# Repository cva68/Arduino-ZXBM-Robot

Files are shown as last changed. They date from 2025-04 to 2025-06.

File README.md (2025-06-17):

# Arduino ZXBM Robot
Chassis, PCB and Software to create an Arduino robot, including a custom motor driver shield based on the [ZXBM5210 motor driver](https://www.diodes.com/assets/Datasheets/products_inactive_data/ZXBM5210.pdf), and a chassis to hold two ["TT" geared DC motors](https://www.adafruit.com/product/3777). 

The Arduino shield design can be found in [hw](hw), and the robot chassis design can be found in [chassis](/chassis). Modules for interfacing with the shield can be found in [lib](/lib), and example control code is in [src](/src).

## Chassis
This chassis is specifically designed for the **Univeristy of Canterbury** Arduino Uno clone. The mount positions will need to be modified to be used with a standard Arduino Uno.

This is designed for 3D printing. Support will only be needed for the overhangs on the top of the chassis that are used to support the Arduino.

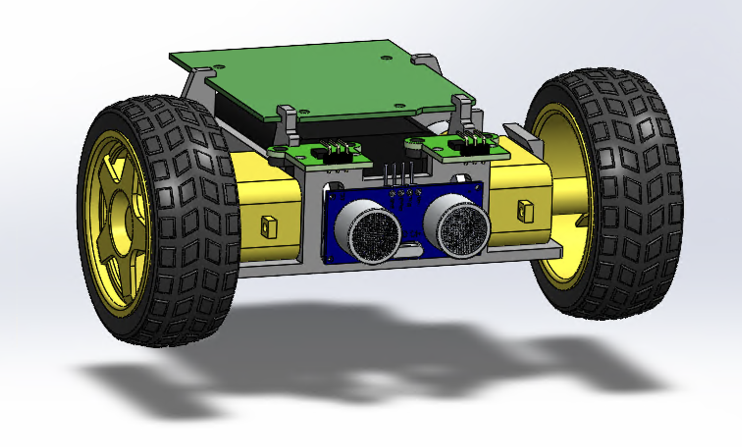
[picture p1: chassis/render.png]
Render of robot chassis


## Control Hardware

Designed in KiCad. [MotorDriverShield.kicad_pcb](hw/MotorDriverShield.kicad_pcb) and [MotorDriverShield.kicad_sch](hw/MotorDriverShield.kicad_sch) can be loaded into KiCad to modify the schematic or export Gerber files.

### Schematic
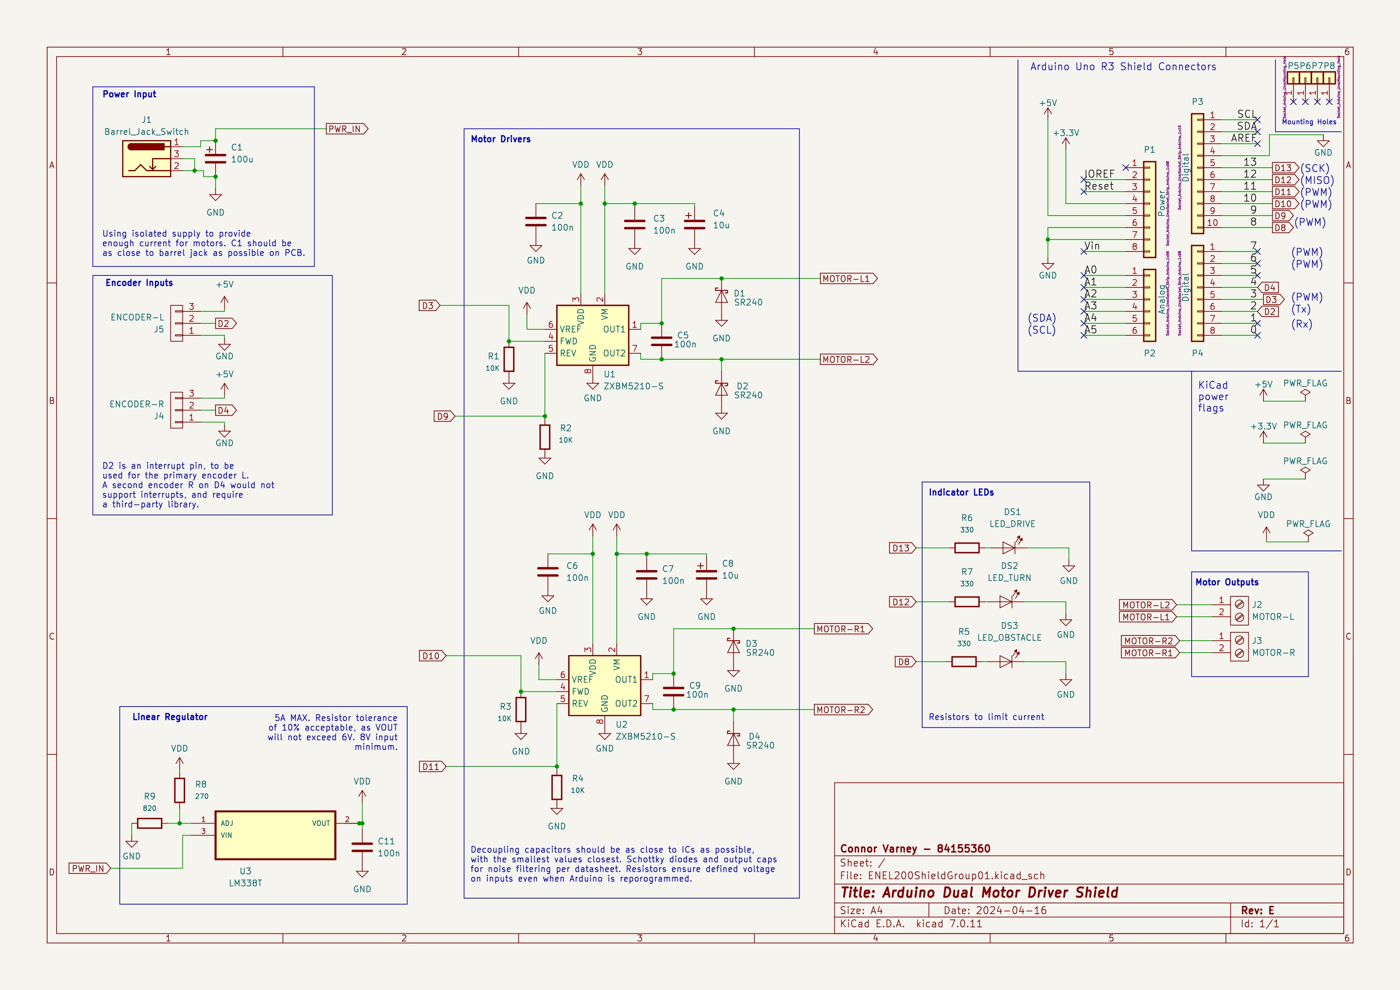
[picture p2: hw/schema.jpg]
Robot Schematic


### PCB
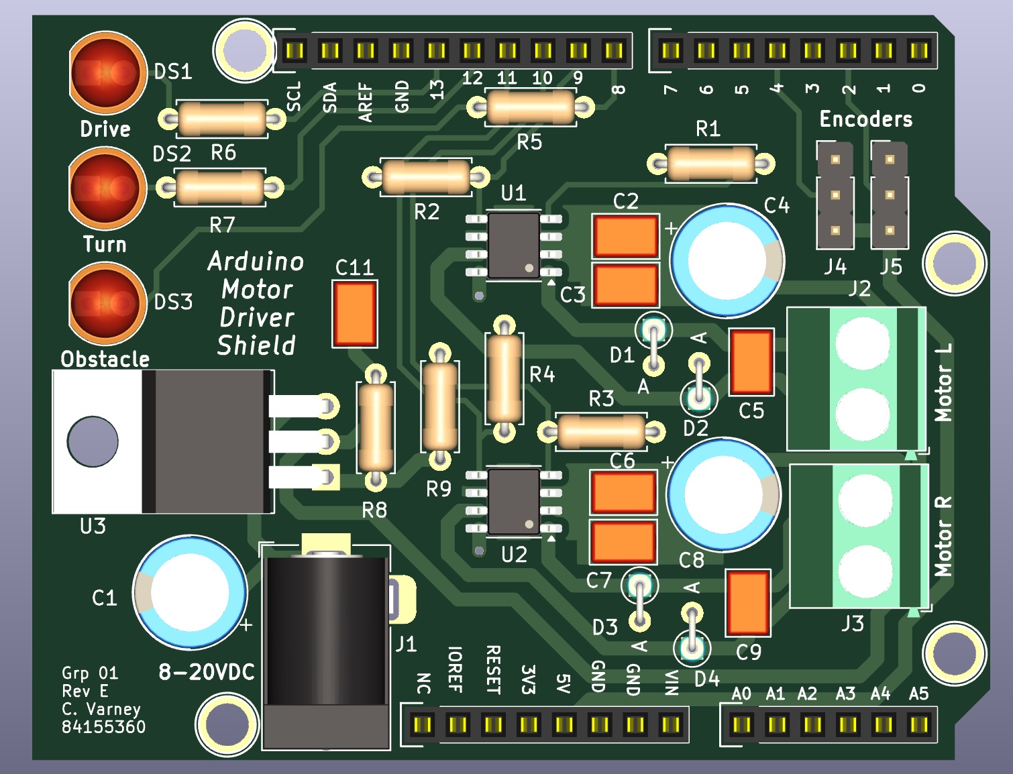
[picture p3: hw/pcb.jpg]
Robot PCB


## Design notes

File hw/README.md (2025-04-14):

# Control Hardware

Designed in KiCad. [MotorDriverShield.kicad_pcb](MotorDriverShield.kicad_pcb) and [MotorDriverShield.kicad_sch](MotorDriverShield.kicad_sch) can be loaded into KiCad to modify the schematic or export Gerber files.

## Schematic
Robot Schematic

## PCB
Robot PCB

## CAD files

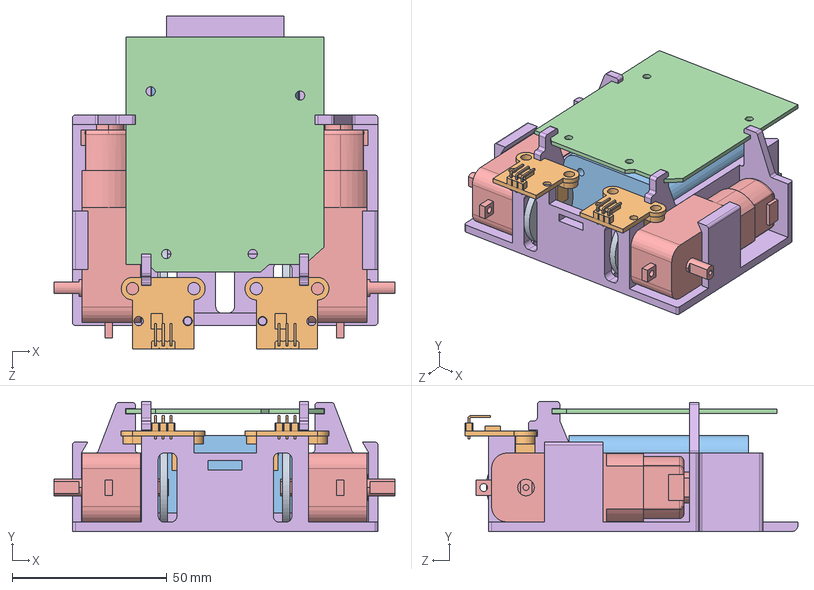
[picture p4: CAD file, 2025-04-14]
chassis/SolidWorks/Assem1.SLDASM
110.2 x 42.0 x 107.6 mm
Chassis1
motor.step x 2
Arduino
Battery
HC_020K x 2
EncoderWheel x 2

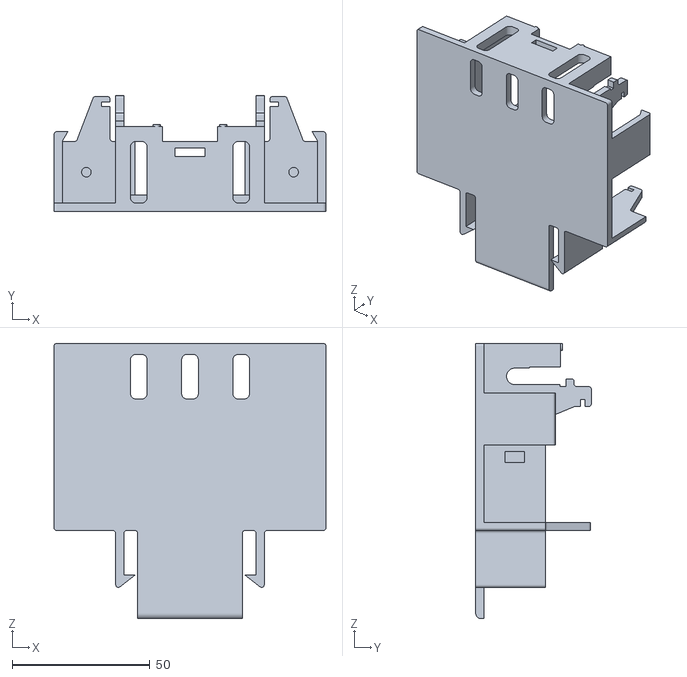
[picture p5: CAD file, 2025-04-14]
chassis/chassis.STL
98.8 x 42.0 x 100.0

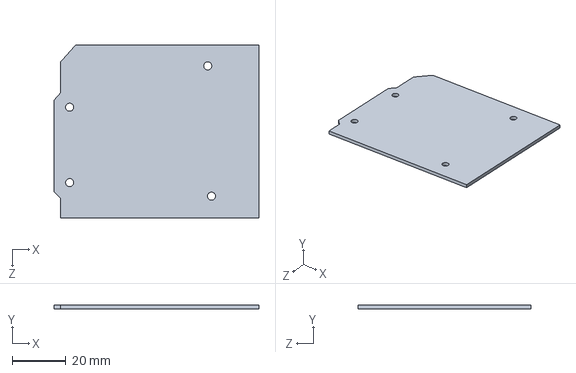
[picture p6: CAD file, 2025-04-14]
chassis/SolidWorks/Arduino.SLDPRT
76.0 x 1.50 x 64.0 mm

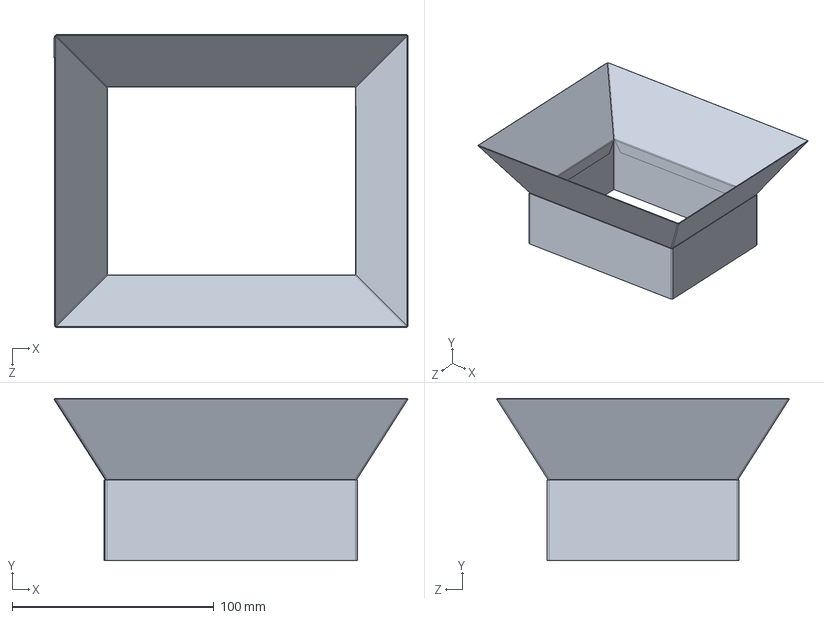
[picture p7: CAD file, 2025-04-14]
chassis/SolidWorks/Part1.SLDPRT
175.4 x 80.3 x 145.0 mm

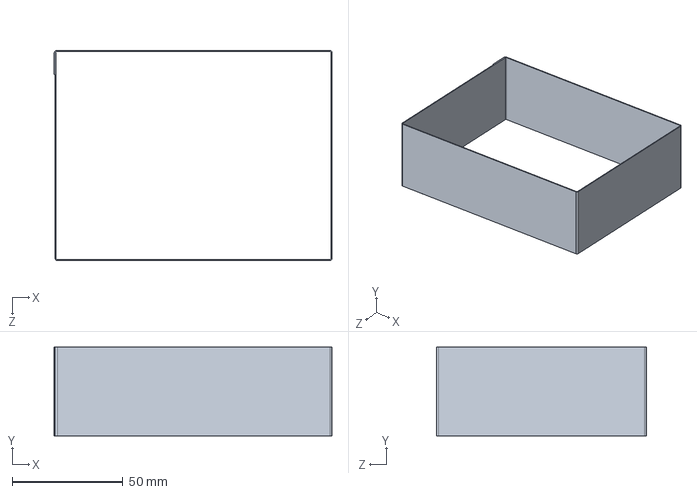
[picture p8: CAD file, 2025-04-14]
chassis/SolidWorks/funnel-bottom.SLDPRT
125.5 x 40.0 x 95.0 mm

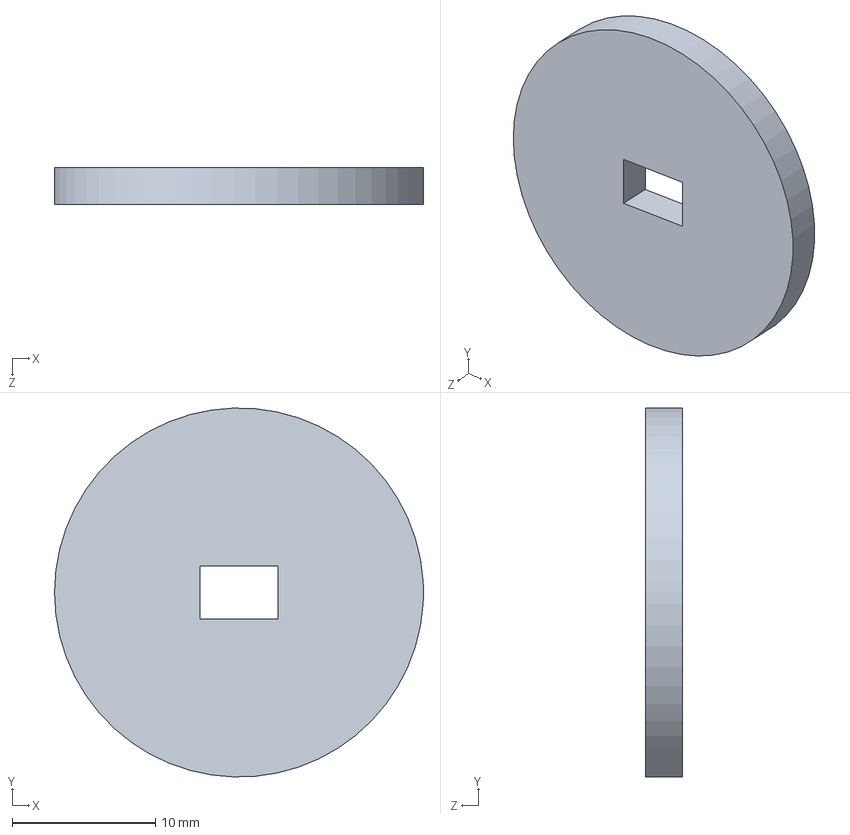
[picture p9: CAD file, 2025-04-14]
chassis/SolidWorks/EncoderWheel.SLDPRT
25.8 x 25.7 x 2.55 mm

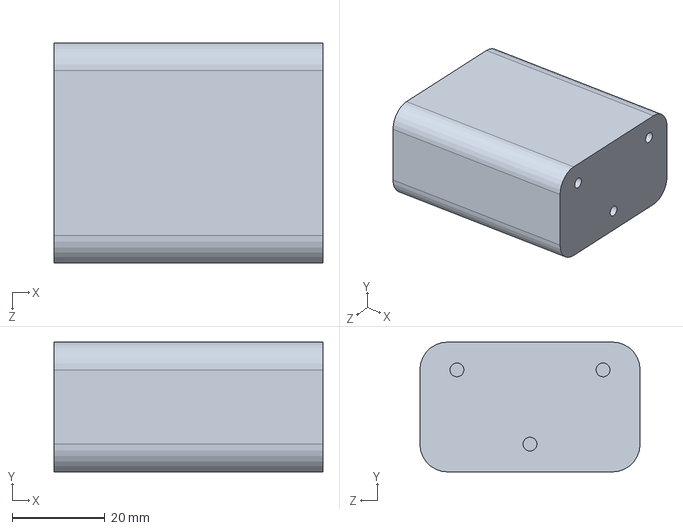
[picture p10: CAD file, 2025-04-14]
chassis/SolidWorks/Battery.SLDPRT
58.0 x 28.0 x 47.5 mm

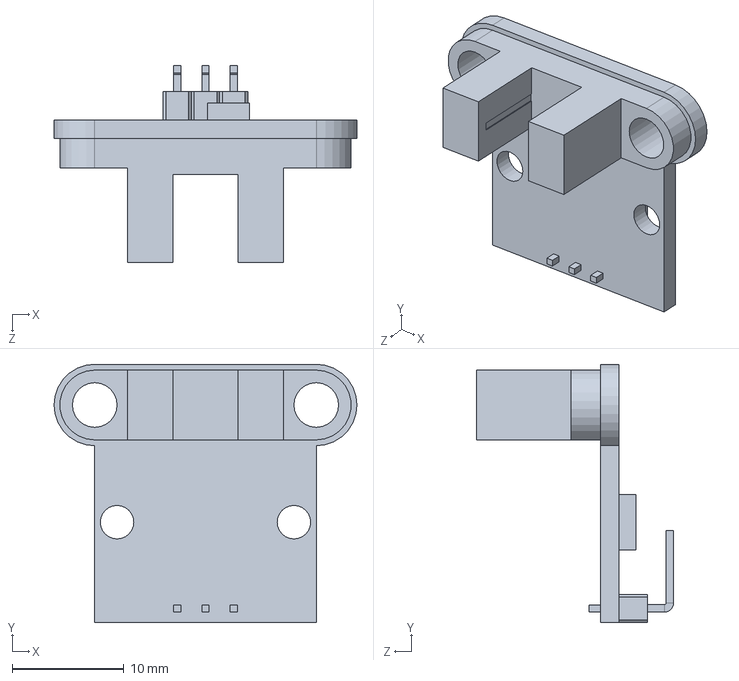
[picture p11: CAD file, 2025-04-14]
chassis/SolidWorks/HC_020K.SLDPRT
27.1 x 23.2 x 17.7 mm

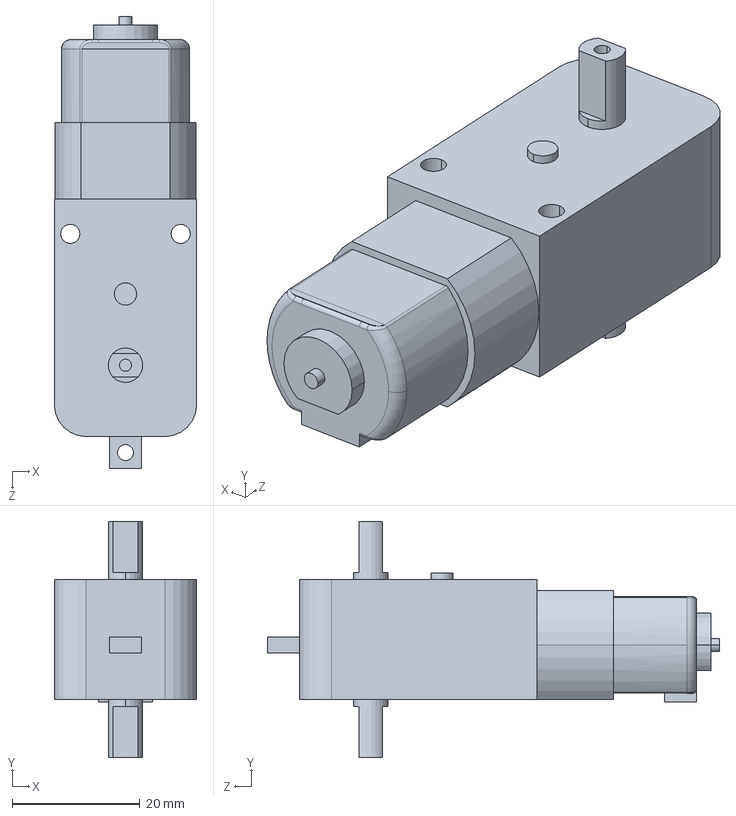
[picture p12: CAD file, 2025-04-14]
chassis/SolidWorks/motor.step.SLDPRT
22.3 x 37.0 x 70.8 mm

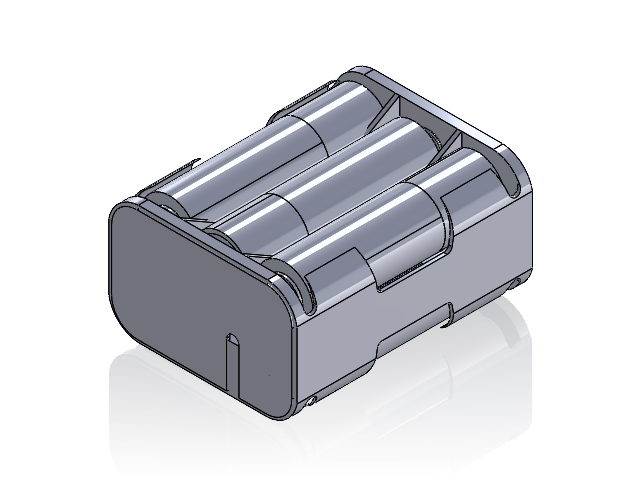
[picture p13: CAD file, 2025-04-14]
chassis/SolidWorks/BatteryHolder6xAA.SLDASM
CELECPORTABATERIAS._MAQUINADA.stp_Predeterminado.STEP
CELECTAPA PORTA BATERIAS_MAQUINADA.stp_Predeterminado.STEP
CELECTAPA PORTA BATERIAS_Superior_MAQUINADA.stp_Predeterminado.STEP
CELECESPIRAL_CON ESTRELLA.stp_Predeterminado.STEP x 5
CELECESTRELLA_A.stp_Predeterminado.STEP
CELECESPIRAL_A..stp_Predeterminado.STEP
Pila AA_Predeterminado.STEP x 6

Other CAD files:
chassis/SolidWorks/Chassis1.SLDPRT
chassis/SolidWorks/Chassis.SLDDRW
chassis/SolidWorks/EntireAssembly.SLDDRW
chassis/SolidWorks/Exploded.SLDDRW
chassis/SolidWorks/Part1.SLDDRW

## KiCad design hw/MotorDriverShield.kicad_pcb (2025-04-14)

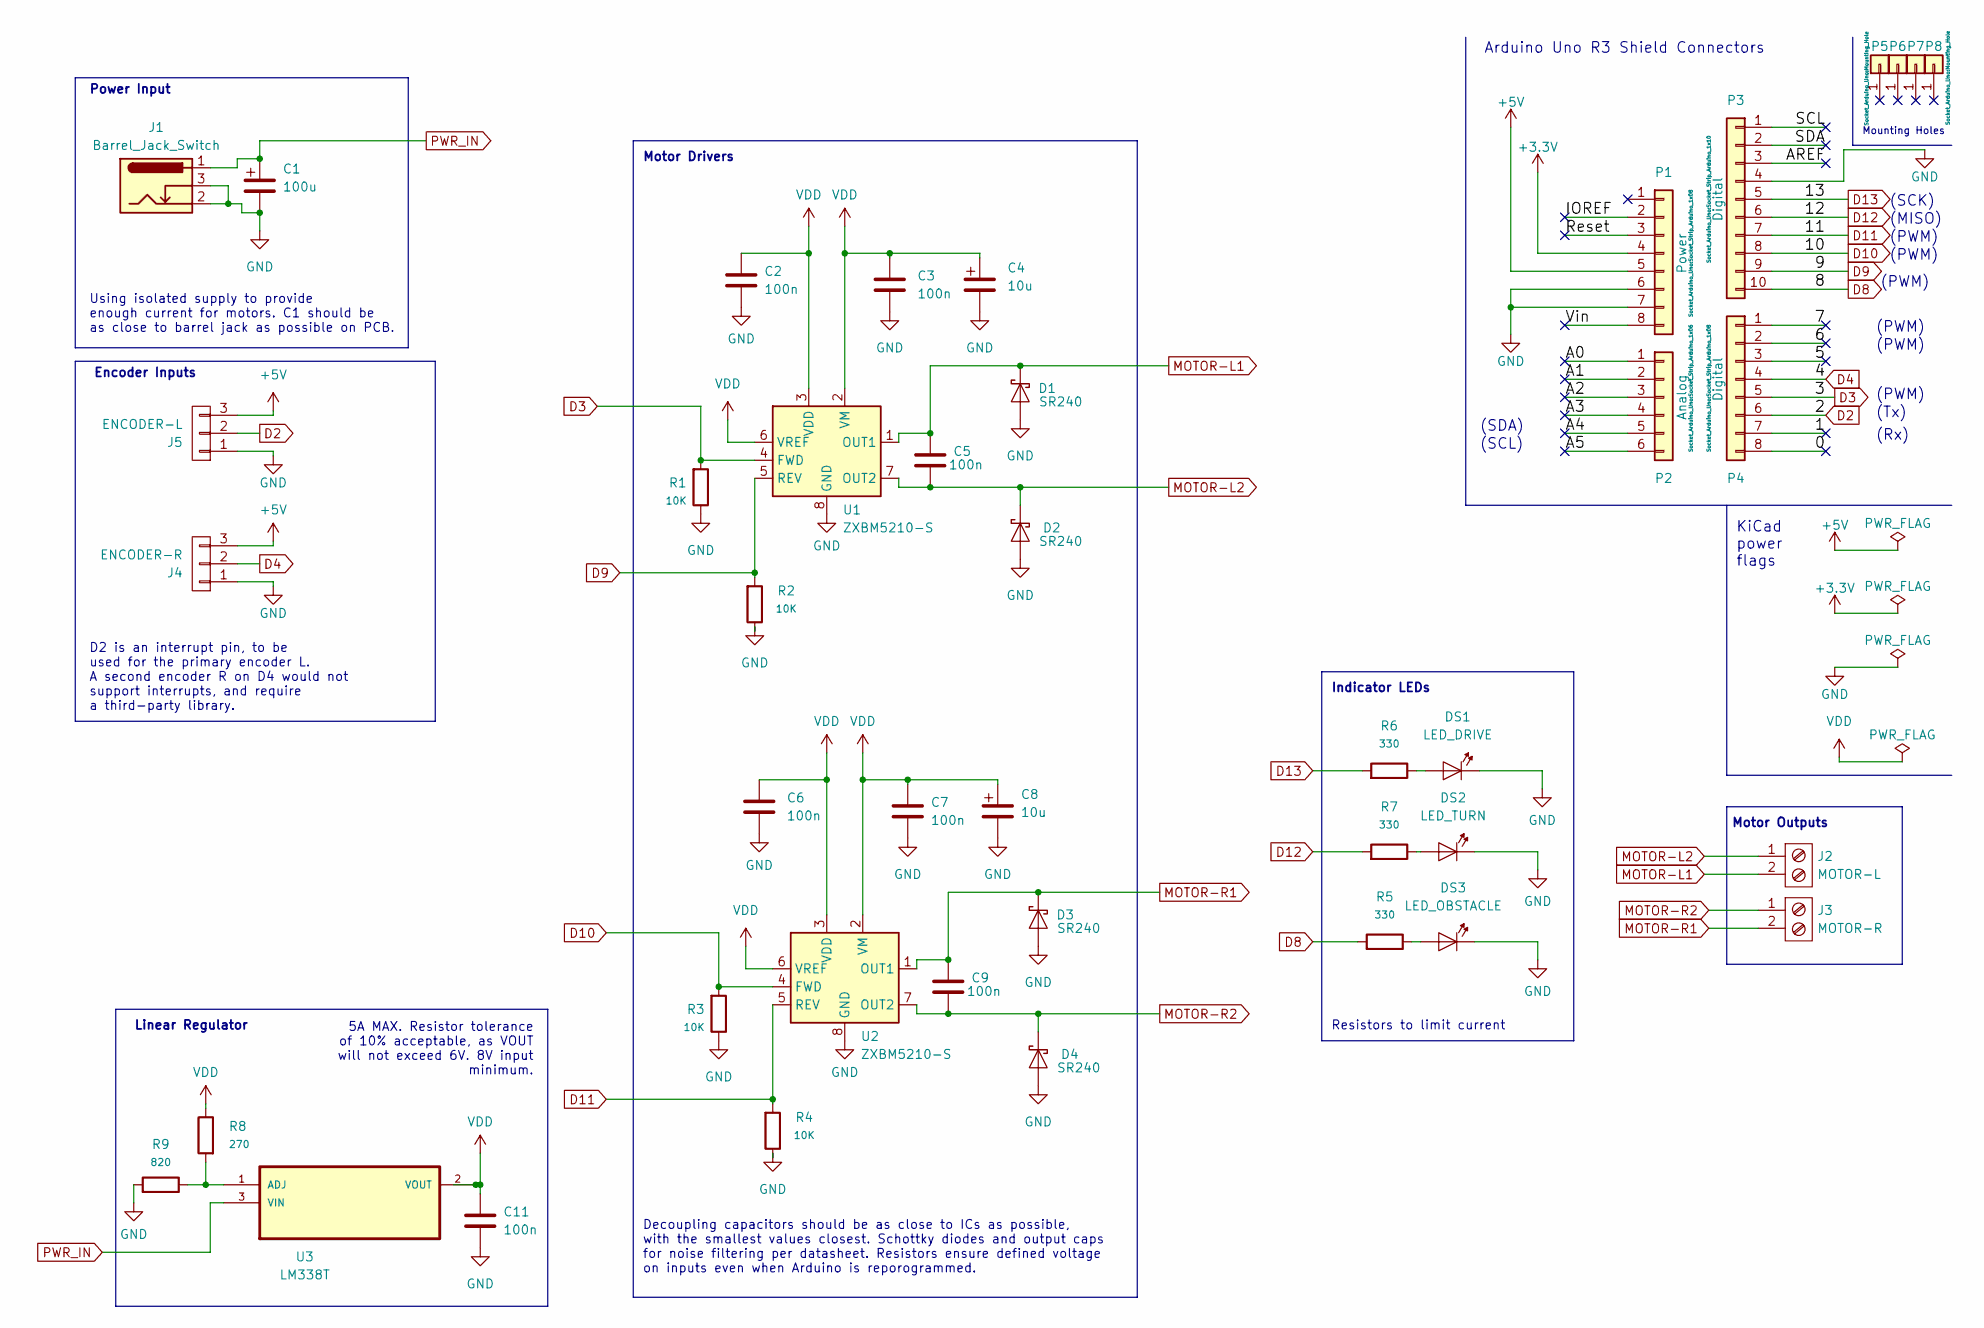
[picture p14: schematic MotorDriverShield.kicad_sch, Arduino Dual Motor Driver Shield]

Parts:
C1: 100u; CP_Radial_D8.0mm_P3.50mm
C2, C3, C5, C6, C7, C9, C11: 100n; C_Rect_L4.6mm_W3.0mm_P2.50mm_MKS02_FKP02
C4, C8: 10u; CP_Radial_D8.0mm_P3.50mm
D1, D2, D3, D4: SR240; D_DO-35_SOD27_P2.54mm_Vertical_AnodeUp
DS1: LED_DRIVE; LED_D5.0mm
DS2: LED_TURN; LED_D5.0mm
DS3: LED_OBSTACLE; LED_D5.0mm
J1: Barrel_Jack_Switch; BarrelJack_Horizontal
J2: MOTOR-L; TerminalBlock_Phoenix_MKDS-1,5-2-5.08_1x02_P5.08mm_Horizont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
J3: MOTOR-R; TerminalBlock_Phoenix_MKDS-1,5-2-5.08_1x02_P5.08mm_Horizont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
J4: ENCODER-R; PinHeader_1x03_P2.54mm_Vertical
J5: ENCODER-L; PinHeader_1x03_P2.54mm_Vertical
P1: Power; Socket_Strip_Arduino_1x08
P2: Analog; Socket_Strip_Arduino_1x06
P3: Digital; Socket_Strip_Arduino_1x10
P4: Digital; Socket_Strip_Arduino_1x08
P5, P6, P7, P8: CONN_01X01; Mounting_Hole
R1, R2, R3, R4: 10K; R_Axial_DIN0207_L6.3mm_D2.5mm_P7.62mm_Horizontal
R5, R6, R7: 330; R_Axial_DIN0207_L6.3mm_D2.5mm_P7.62mm_Horizontal
R8: 270; R_Axial_DIN0207_L6.3mm_D2.5mm_P7.62mm_Horizontal
R9: 820; R_Axial_DIN0207_L6.3mm_D2.5mm_P7.62mm_Horizontal
U1, U2: ZXBM5210-S; SOIC-8_3.9x4.9mm_P1.27mm
U3: LM338T; TO-220-3_Horizontal_TabDown

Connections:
+3.3V: P1.4
+5V: J4.3, J5.3, P1.5
/0: P4.8
/1: P4.7
/5: P4.3
/6: P4.2
/7: P4.1
/A0: P2.1
/A1: P2.2
/A2: P2.3
/A3: P2.4
/A4: P2.5
/A5: P2.6
/AREF: P3.3
/IOREF: P1.2
/Reset: P1.3
/SCL: P3.1
/SDA: P3.2
/Vin: P1.8
D2: J5.2, P4.6
D3: P4.5, R1.1, U1.4 (FWD)
D4: J4.2, P4.4
D8: P3.10, R5.1
D9: P3.9, R2.1, U1.5 (REV)
D10: P3.8, R3.1, U2.4 (FWD)
D11: P3.7, R4.1, U2.5 (REV)
D12: P3.6, R7.1
D13: P3.5, R6.1
GND: C1.2, C2.2, C3.2, C4.2, C6.2, C7.2, C8.2, C11.2, D1.2 (A), D2.2 (A), D3.2 (A), D4.2 (A), DS1.1 (K), DS2.1 (K), DS3.1 (K), J1.2, J1.3, J4.1, J5.1, P1.6, P1.7, P3.4, R1.2, R2.2, R3.2, R4.2, R9.1, U1.8 (GND), U2.8 (GND)
MOTOR-L1: C5.1, D1.1 (K), J2.2, U1.1 (OUT1)
MOTOR-L2: C5.2, D2.1 (K), J2.1, U1.7 (OUT2)
MOTOR-R1: C9.1, D3.1 (K), J3.2, U2.1 (OUT1)
MOTOR-R2: C9.2, D4.1 (K), J3.1, U2.7 (OUT2)
unnamed: DS1.2 (A), R6.2
unnamed: DS2.2 (A), R7.2
unnamed: DS3.2 (A), R5.2
unnamed: R8.1, R9.2, U3.1 (ADJ)
PWR_IN: C1.1, J1.1, U3.3 (VIN)
VDD: C2.1, C3.1, C4.1, C6.1, C7.1, C8.1, C11.1, R8.2, U1.2 (VM), U1.3 (VDD), U1.6 (VREF), U2.2 (VM), U2.3 (VDD), U2.6 (VREF), U3.2 (VOUT)

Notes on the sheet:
KiCad power flags
Motor Outputs
(Tx)
Decoupling capacitors should be as close to ICs as possible, with the smallest values closest. Schottky diodes and output caps for noise filtering per datasheet. Resistors ensure defined voltage on inputs even when Arduino is reporogrammed.
(SCK)
Encoder Inputs
Indicator LEDs
5A MAX. Resistor tolerance of 10% acceptable, as VOUT will not exceed 6V. 8V input minimum.
Using isolated supply to provide enough current for motors. C1 should be as close to barrel jack as possible on PCB.
(PWM)
(Rx)
Resistors to limit current
Arduino Uno R3 Shield Connectors
(SCL)
(MISO)
Mounting Holes
(SDA)
Linear Regulator
D2 is an interrupt pin, to be used for the primary encoder L. A second encoder R on D4 would not support interrupts, and require a third-party library.
Power Input
Motor Drivers

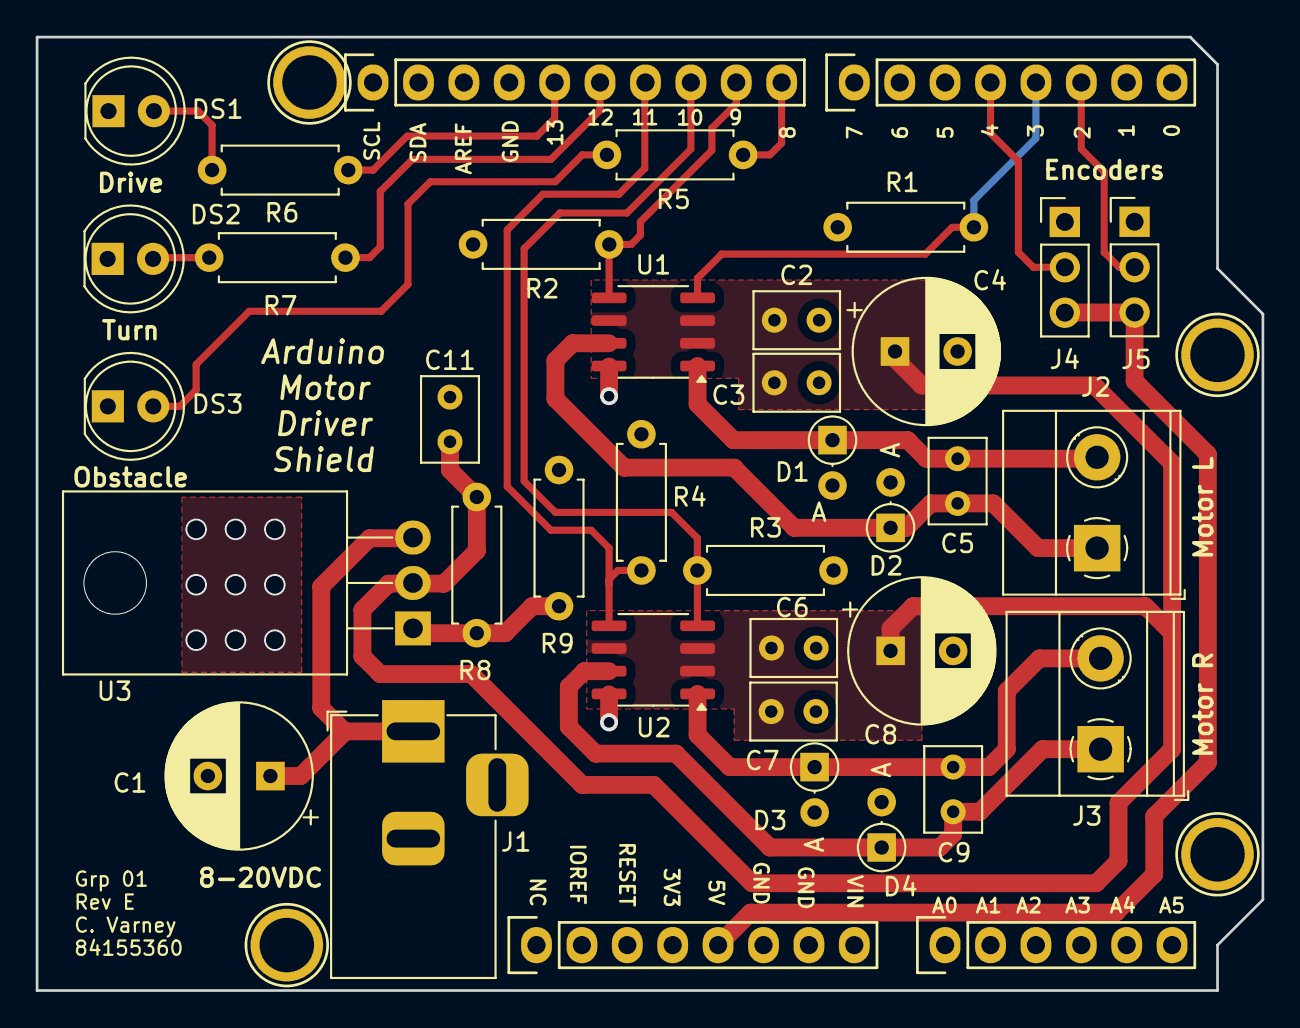
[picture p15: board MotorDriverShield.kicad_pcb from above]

Board: 2 copper layers, 68.6 x 53.3 mm, 42 parts (0 on the bottom side), 21 nets.
